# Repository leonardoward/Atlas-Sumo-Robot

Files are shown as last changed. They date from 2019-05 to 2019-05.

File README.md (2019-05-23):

# Atlas-Sumo-Robot

Software files for a Sumo Robot named Atlas, 2nd place in the VI National Robotics Competition, Sumo Category,  Venezuela 2016.

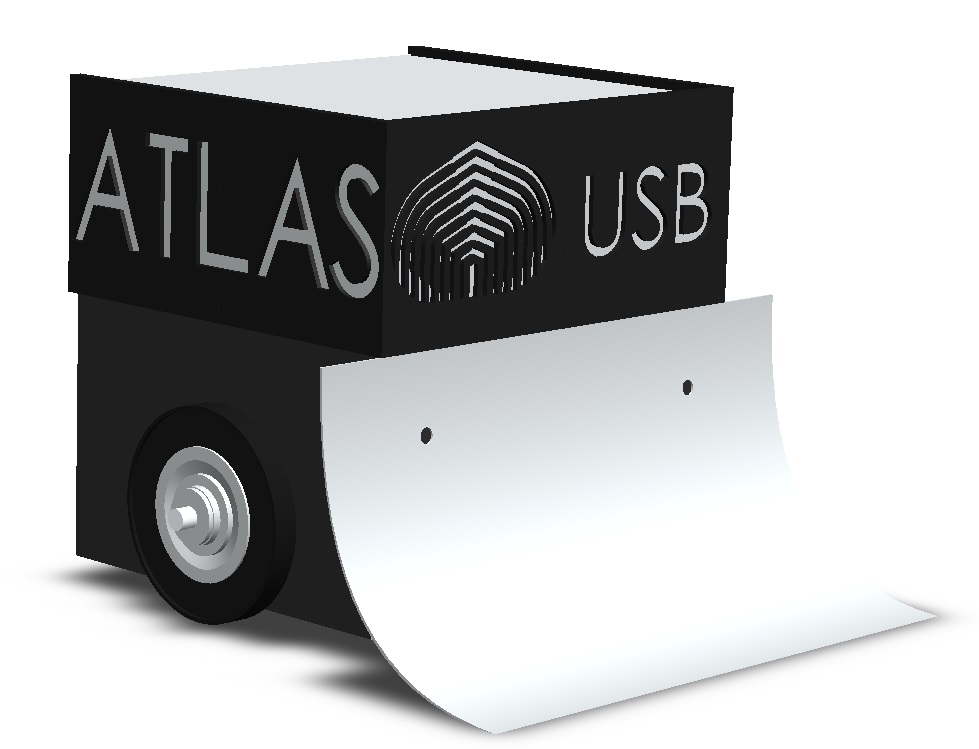
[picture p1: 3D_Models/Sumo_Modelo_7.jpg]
3D Model


## Authors

* **Leonardo Ward** -  [Github](https://github.com/leonardoward)
* **Javier Inojosa** -  [Github](https://github.com/javierinojosa)

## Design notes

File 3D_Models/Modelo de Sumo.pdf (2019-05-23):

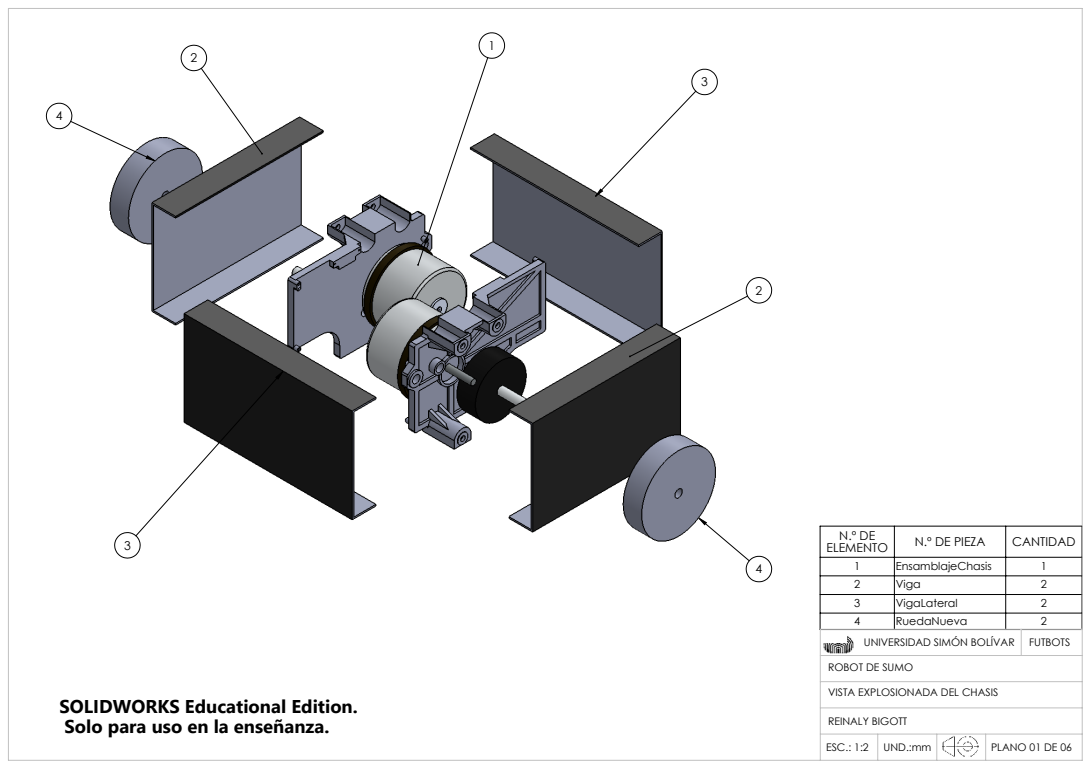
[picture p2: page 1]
REINALY BIGOTT; ESC.: 1:2; UND.:mm; PLANO 01 DE 06

N.º DE ELEMENTO | N.º DE PIEZA | CANTIDAD

1 | EnsamblajeChasis | 1
2 | Viga | 2
3 | VigaLateral | 2
4 | RuedaNueva | 2
UNIVERSIDAD SIMÓN BOLÍVAR | FUTBOTS

ROBOT DE SUMO
VISTA EXPLOSIONADA DEL CHASIS

SOLIDWORKS Educational Edition.
Solo para uso en la enseñanza.

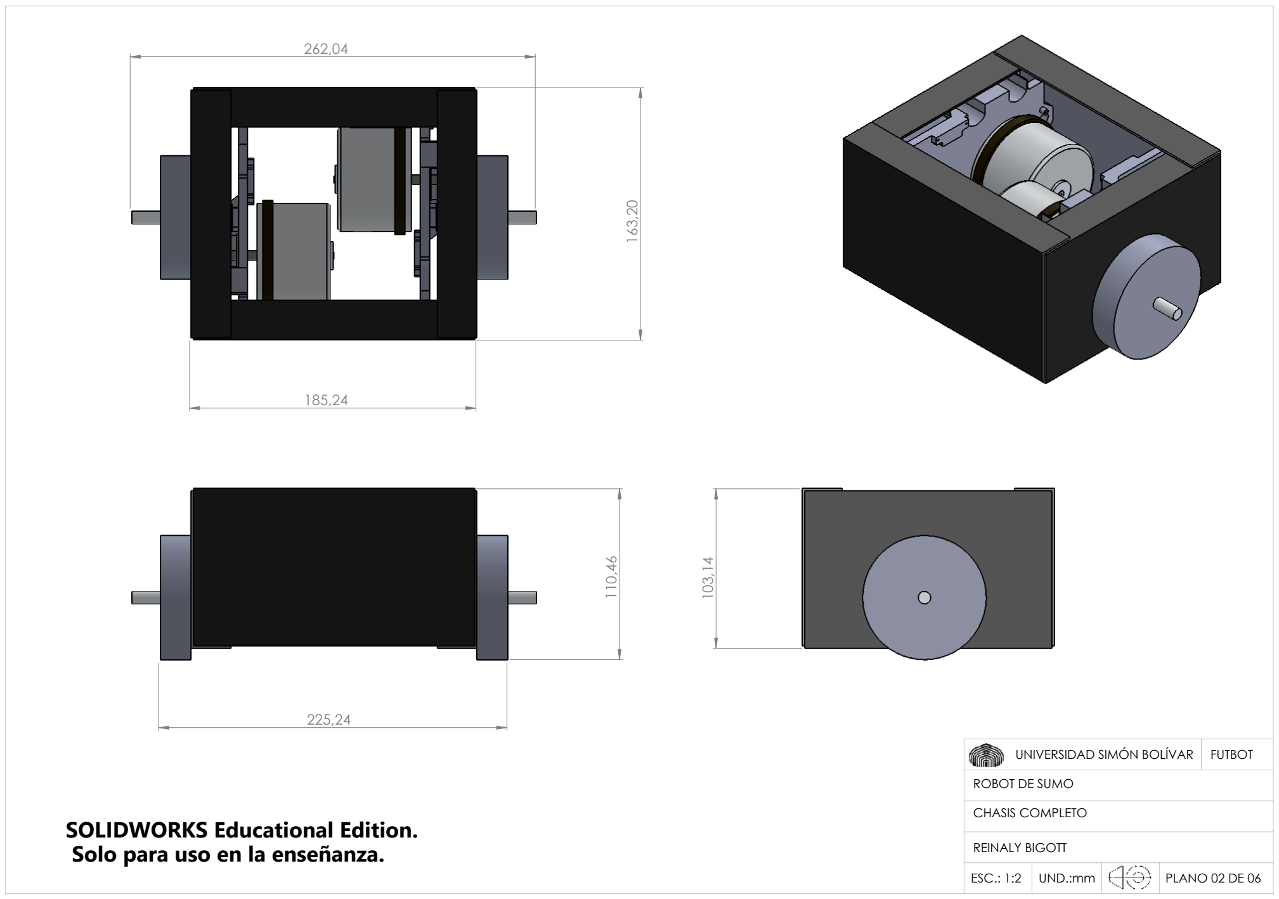
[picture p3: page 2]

225,24

110,46

163,20

185,24

103,14

UNIVERSIDAD SIMÓN BOLÍVAR FUTBOT ROBOT DE SUMO
CHASIS COMPLETO
SOLIDWORKS Educational Edition.

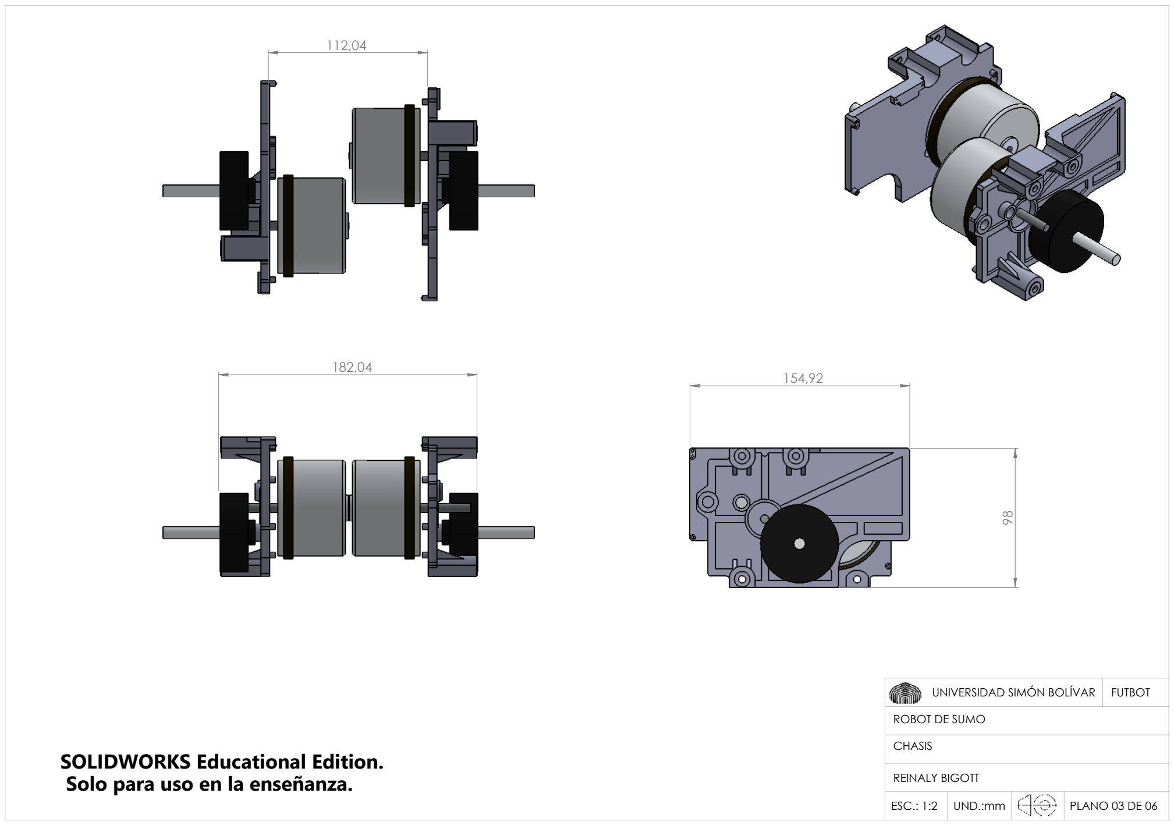
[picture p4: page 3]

182,04
154,92

98

UNIVERSIDAD SIMÓN BOLÍVAR FUTBOT ROBOT DE SUMO
CHASIS
SOLIDWORKS Educational Edition.

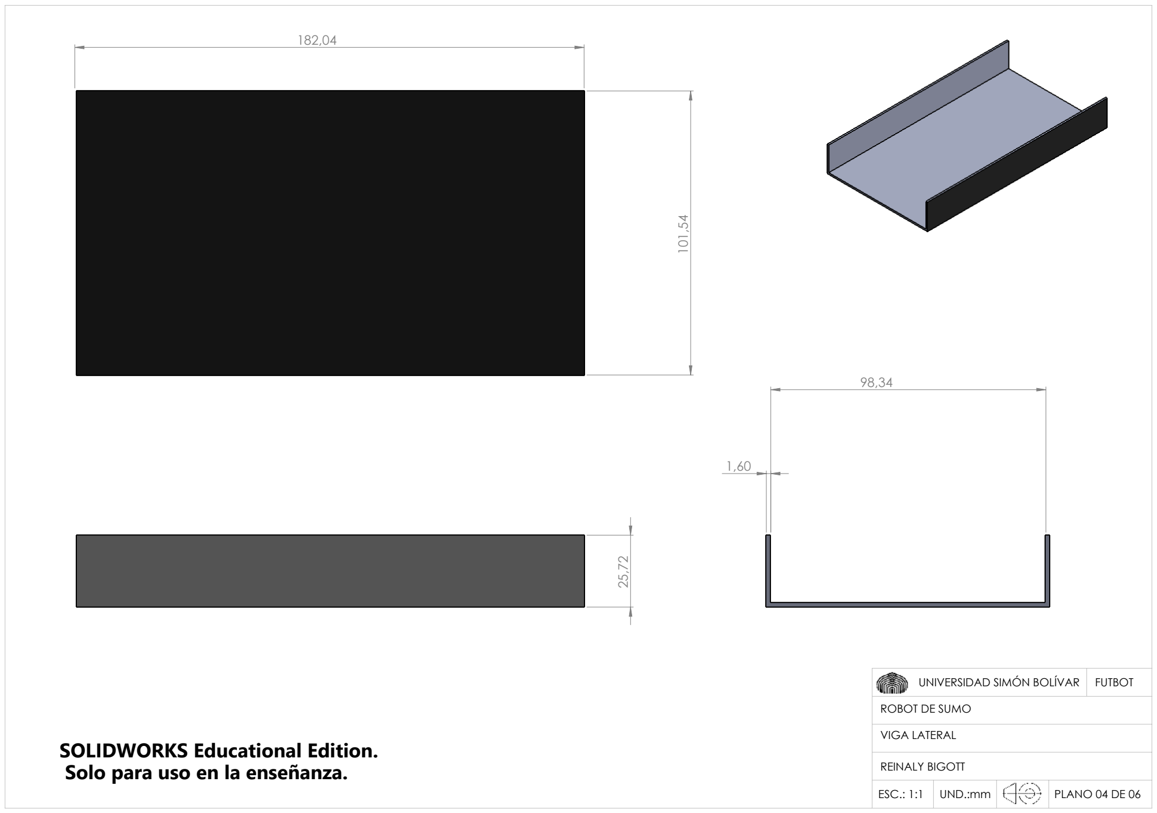
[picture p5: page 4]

25,72

101,54

1,60

98,34

UNIVERSIDAD SIMÓN BOLÍVAR FUTBOT ROBOT DE SUMO
VIGA LATERAL
ESC.: 1:1 | UND.:mm | PLANO 04 DE 06

SOLIDWORKS Educational Edition.

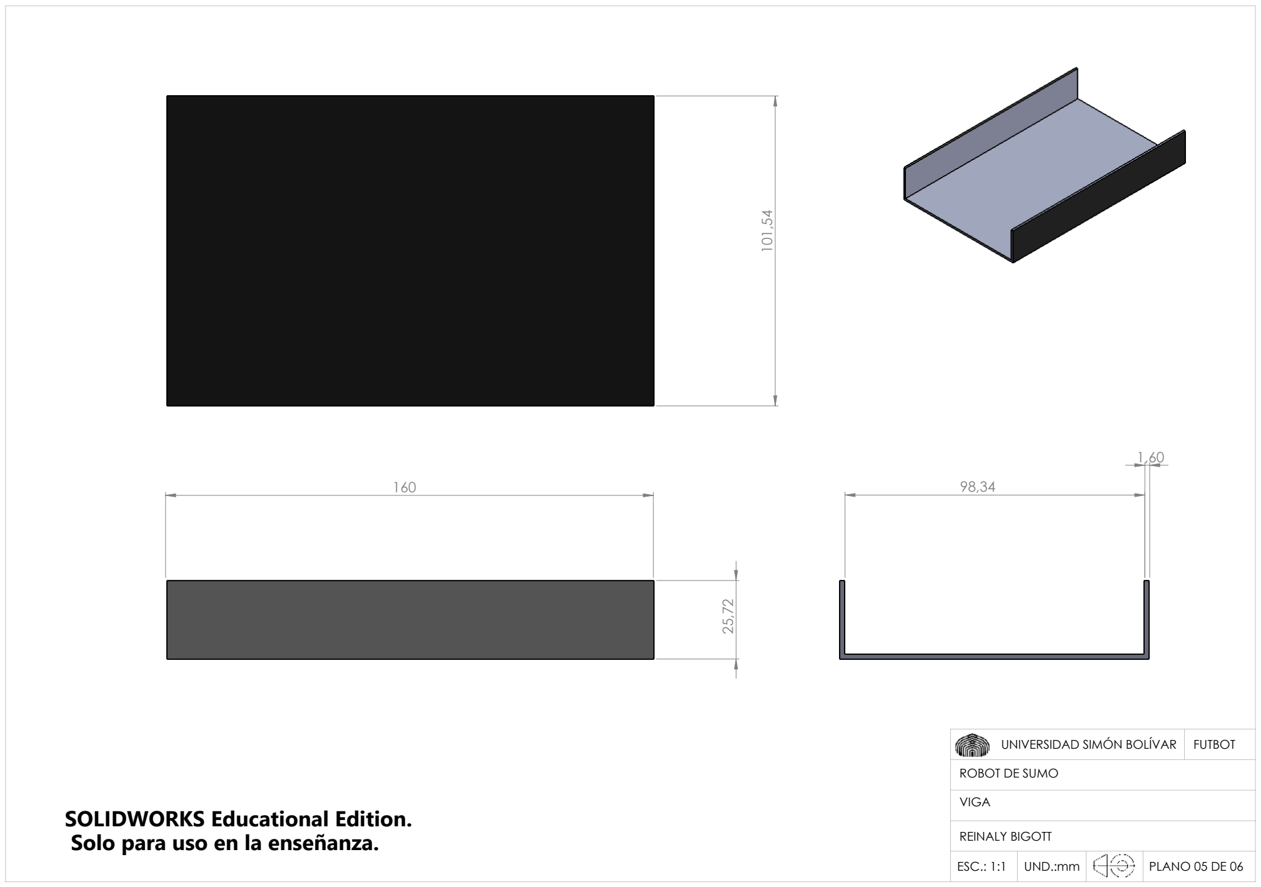
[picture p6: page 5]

160

25,72

98,34

1,60

101,54

UNIVERSIDAD SIMÓN BOLÍVAR FUTBOT ROBOT DE SUMO
VIGA
ESC.: 1:1 | UND.:mm | PLANO 05 DE 06

SOLIDWORKS Educational Edition.

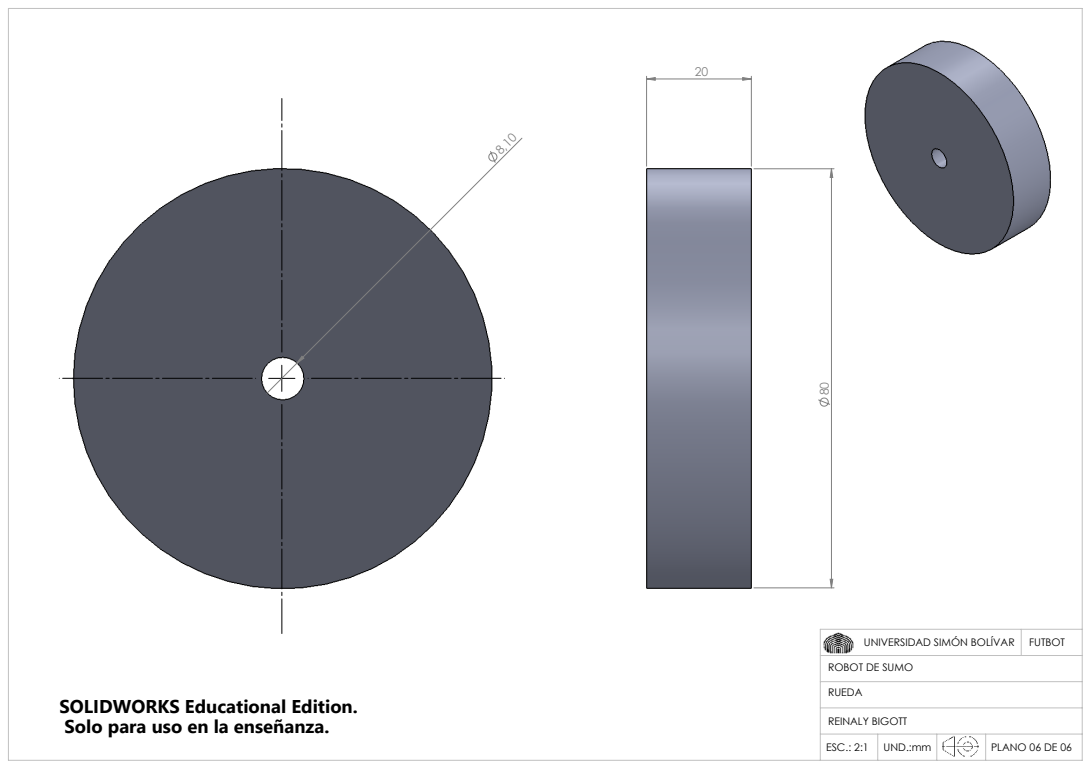
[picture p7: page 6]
UNIVERSIDAD SIMÓN BOLÍVAR; FUTBOT; ESC.: 2:1; UND.:mm; PLANO 06 DE 06

ROBOT DE SUMO
RUEDA

SOLIDWORKS Educational Edition.

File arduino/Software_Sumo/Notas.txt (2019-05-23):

-Todos los robots deben quedar funcionales, y cumplir con lo que se prometió para cada uno
-No va a haber inversión por ahora, por lo menos hasta ver los resultados de la primera inversión,
lo que falte se puede buscar aquí
-Se debe desarmar por completo el submarino para comenzar desde cero, y verificar que ninguna de las piezas
se haya dañado, una vez se verifique que todo lo comprado y las cosas de Pedro se encuentran en buen estado
se podrá comenzar desde cero.
-Es necesario quitarle el negro a todo el submarino de cualquier forma para que luego se pueda pintar del color que
vaya a tener al final, posiblemente amarillo
-Revisar el acrílico, que no debería tener pintura, debería estar en perfecto estado porque se colocó luego de pintar
-Considerar opciones, hacer maquinado con Gearca, pero no vamos a tener dinero para conseguir el material necesario para hacer el maquinado, debemos conseguirlo de cualquier modo, como fundir otras piezas, y si no se puede, entonces no habrá maquinado, tendran que construir cada parte con el aluminio que tenemos o que se pueda conseguir, y se paga la soldadura
-Se espera que el submarino se sumerja 10 o 20 metros
-Montar toda la electrónica fuera del submarino, para verlo todo funcionando, aunque no haya nada de la mecánica
-Análisis hidráulico del submarino

Actividades pendientes:
-Trabajo Cardiotune
-Tesis
-Comentar código del robot de sumo
-Electiva solar

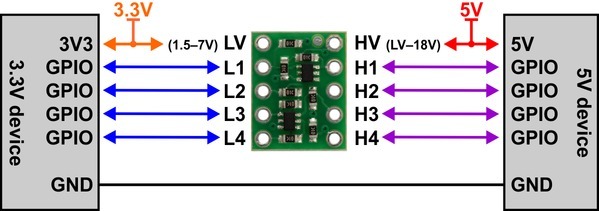
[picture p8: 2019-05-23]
Electronics_Design/Electronica/0J5318.599.jpg

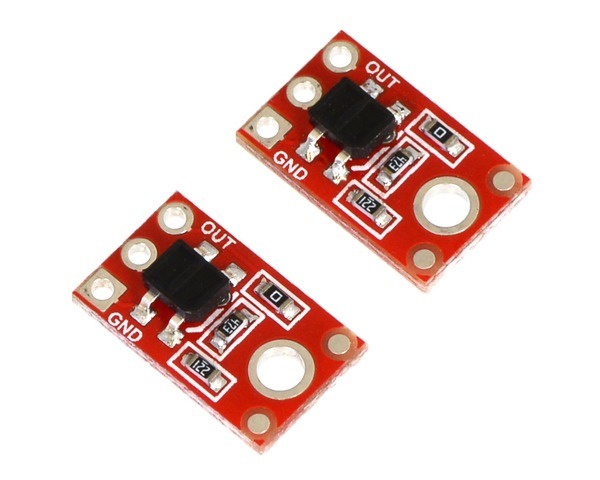
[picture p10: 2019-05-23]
Electronics_Design/Electronica/QTR-1A reflectance sensors.jpg

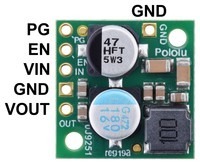
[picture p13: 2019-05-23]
Electronics_Design/Electronica/0J6802.200.jpg

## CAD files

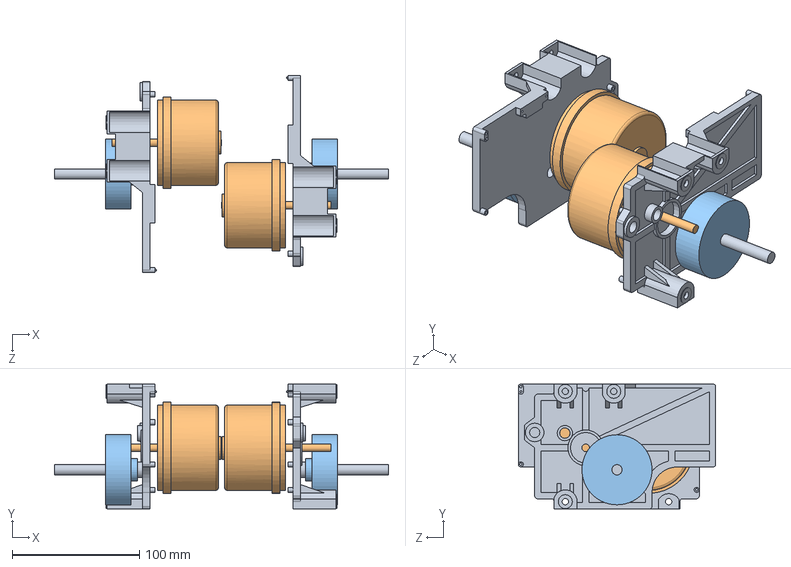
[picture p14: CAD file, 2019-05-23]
3D_Models/Version 3/EnsamblajeChasis.SLDASM
262.0 x 98.0 x 154.9 mm
BaseMotorDeSumo-Copia x 2
MotorDeSumo x 2
EngranajeNegroCentralModificado x 2

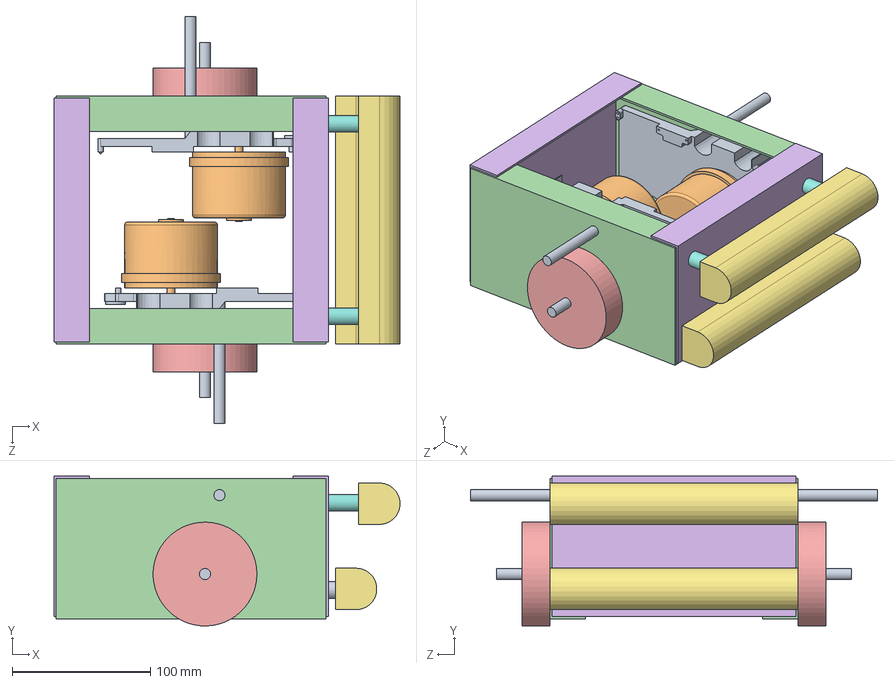
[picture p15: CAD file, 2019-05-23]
3D_Models/Rampa Alternativa/EnsamblajeNuevoConRampa.SLDASM
249.9 x 108.3 x 294.0 mm
BaseMotorDeSumo x 2
MotorDeSumo x 2
EngranajeNegroCentralModificado x 2
Viga x 2
RuedaNueva x 2
VigaLateral x 2
PiezaDeBloqueo x 2
Tubo x 2
Tubo2 x 2

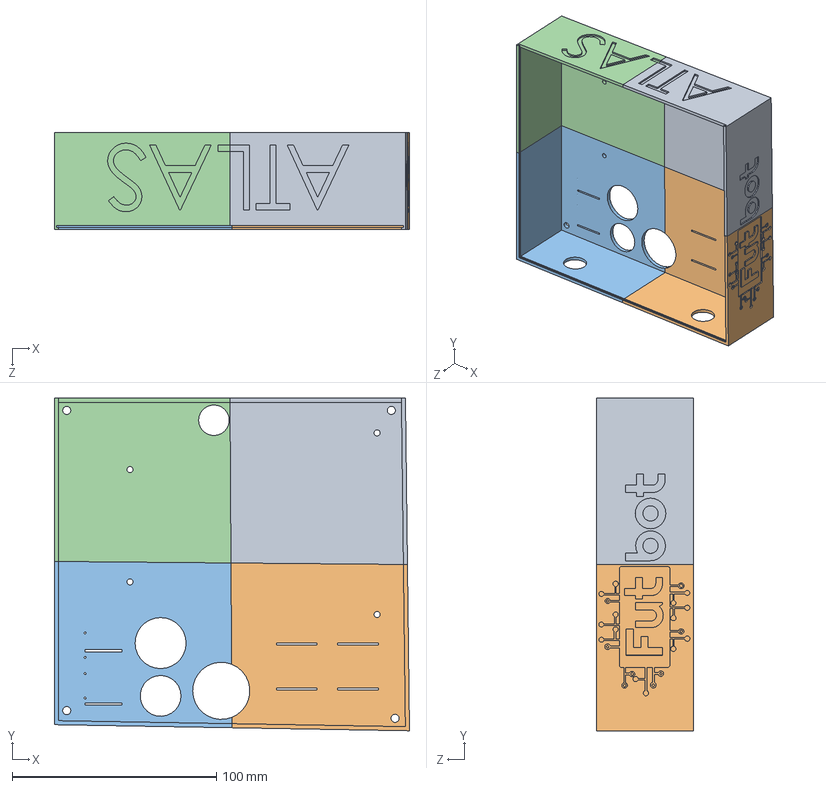
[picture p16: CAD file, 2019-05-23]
3D_Models/Caja y rueda/Caja 3D.SLDASM
174.0 x 163.0 x 47.5 mm
Pieza N°1
Pieza N°2
Pieza N°3
Pieza N°4

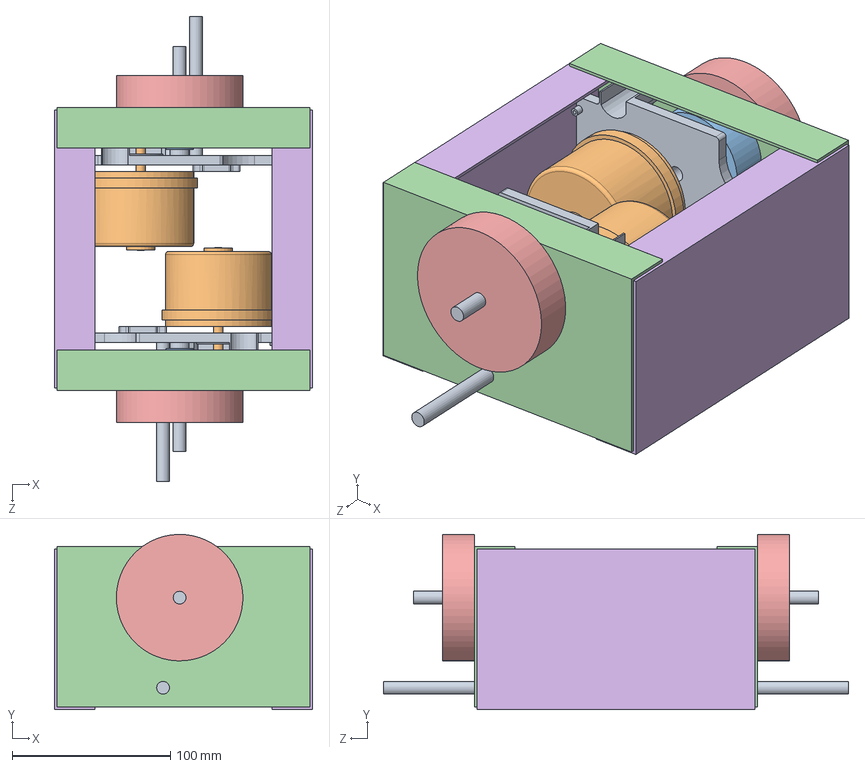
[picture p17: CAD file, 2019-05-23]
3D_Models/Version 3/EnsamblajeNuevoChasis.SLDASM
163.2 x 110.8 x 294.0 mm
BaseMotorDeSumo x 2
MotorDeSumo x 2
EngranajeNegroCentralModificado x 2
Viga x 2
RuedaNueva x 2
VigaLateral x 2

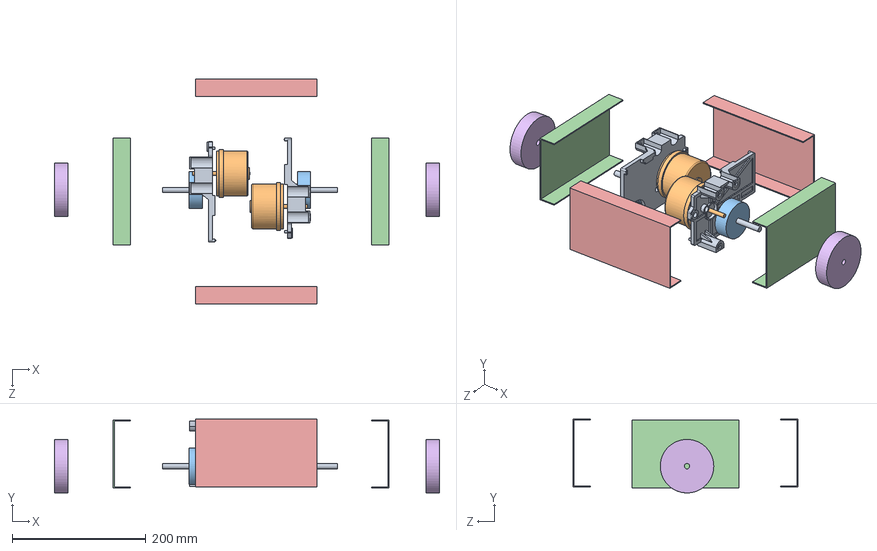
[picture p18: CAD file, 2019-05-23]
3D_Models/Version 3/EnsamblajeChasis1.SLDASM
575.8 x 110.5 x 336.1 mm
BaseMotorDeSumo-Copia x 2
MotorDeSumo x 2
EngranajeNegroCentralModificado x 2
Viga x 2
VigaLateral x 2
RuedaNueva x 2

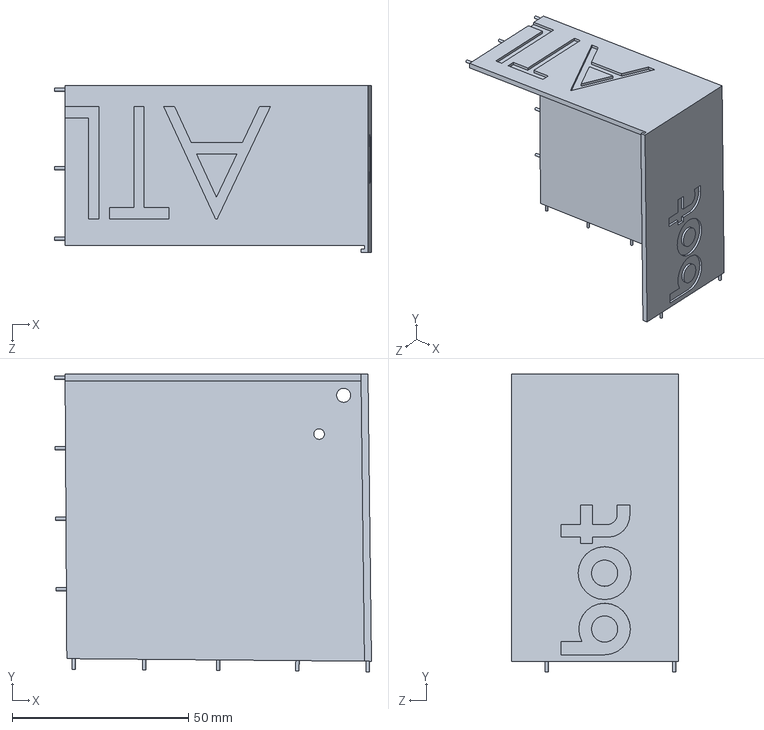
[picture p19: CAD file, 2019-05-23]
3D_Models/Caja y rueda/Pieza N°1.SLDPRT
90.0 x 84.5 x 47.5 mm

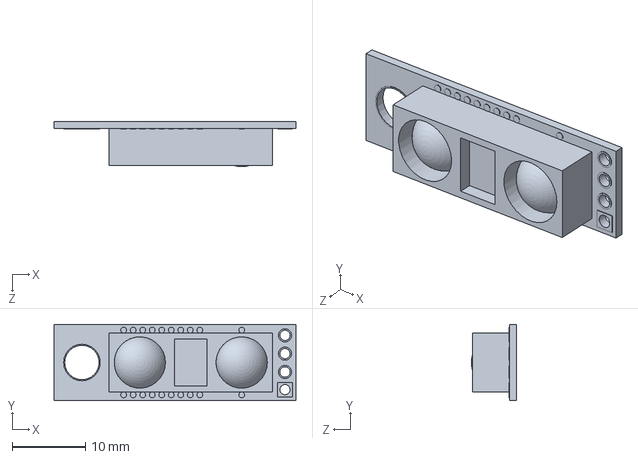
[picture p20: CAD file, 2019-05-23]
3D_Models/Electronica/PololuCarrierWithSharpGP2Y0A60SZLFAnalogDistanceSensor10-150cm,5V.SLDPRT
33.0 x 10.4 x 6.20 mm

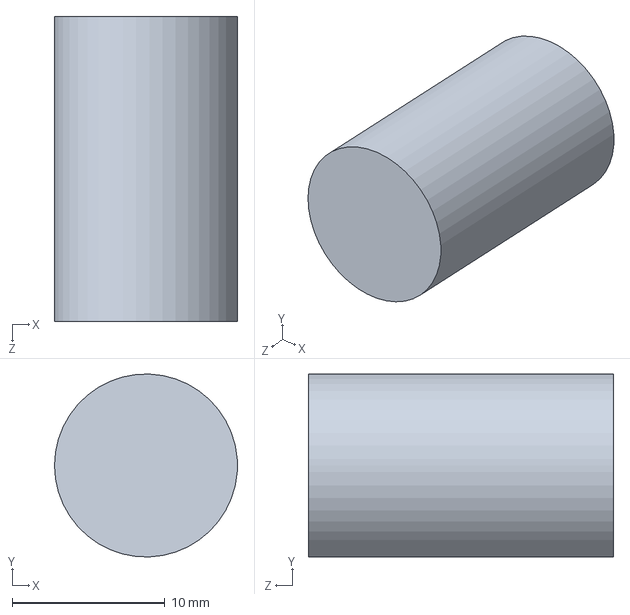
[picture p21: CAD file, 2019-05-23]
3D_Models/Rampa Alternativa/Tubo2.SLDPRT
12.0 x 12.0 x 20.0 mm

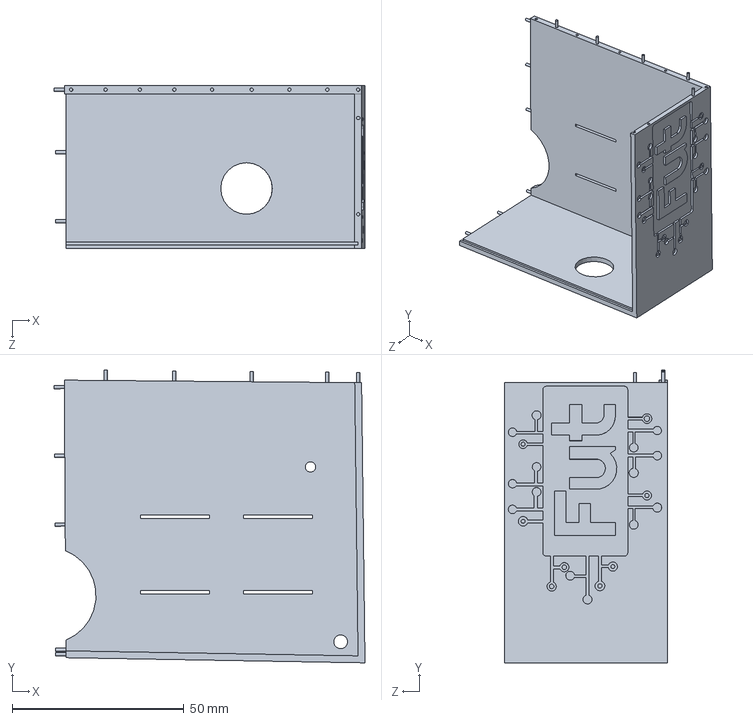
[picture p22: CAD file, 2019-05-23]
3D_Models/Caja y rueda/Pieza N°2.SLDPRT
90.5 x 85.1 x 47.5 mm

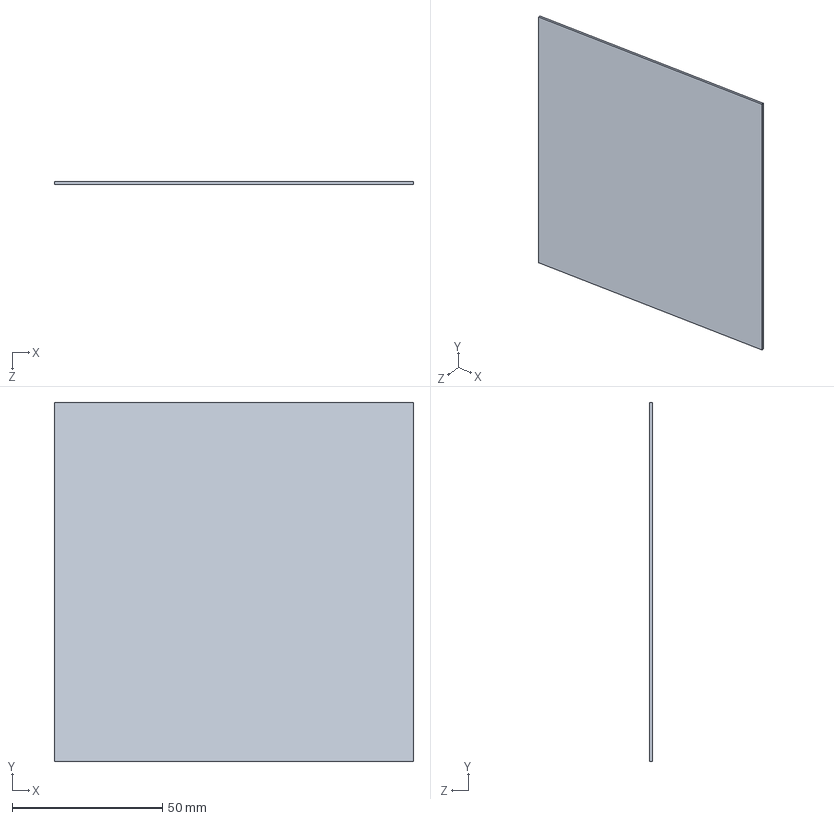
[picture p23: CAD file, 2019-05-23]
3D_Models/Electronica/RaspberryPiCameraModuleV2-8Megapixel,1080p.SLDPRT
119.4 x 119.4 x 1.00 mm

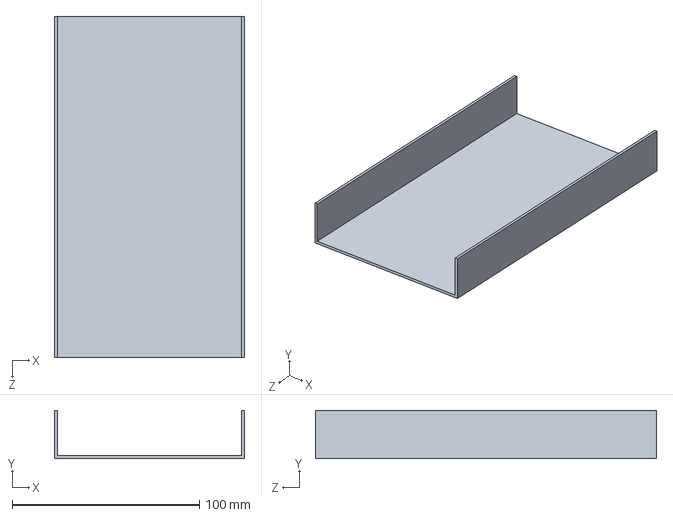
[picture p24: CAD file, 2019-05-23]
3D_Models/Version 3/VigaLateral.SLDPRT
101.5 x 25.7 x 182.0 mm

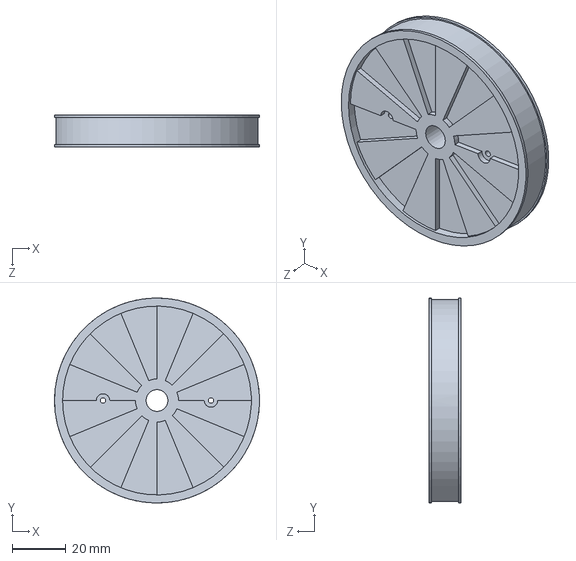
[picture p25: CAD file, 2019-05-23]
3D_Models/Caja y rueda/Rueda 3D.SLDPRT
76.0 x 76.0 x 12.0 mm

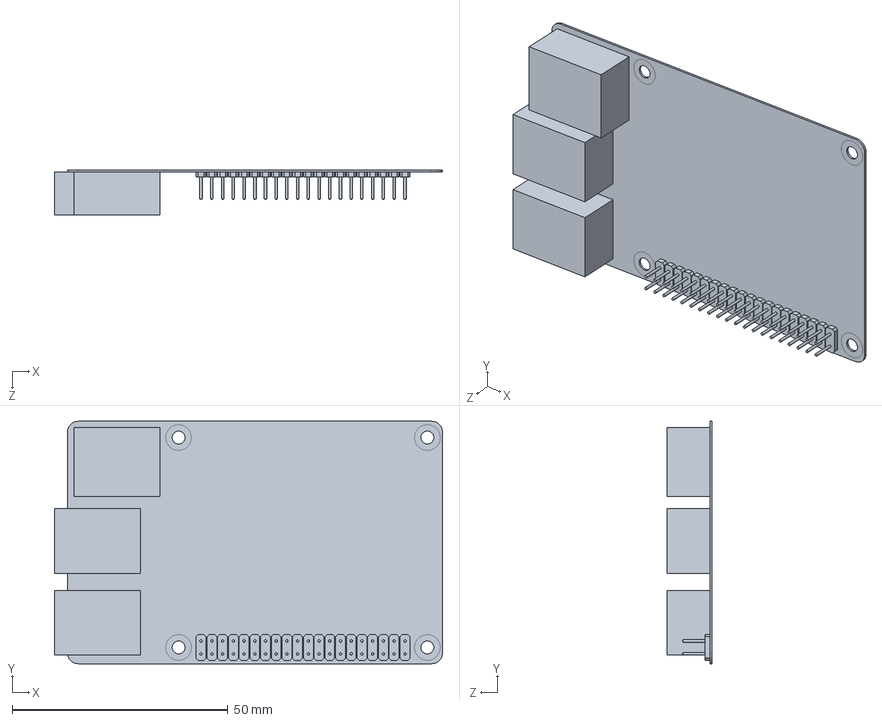
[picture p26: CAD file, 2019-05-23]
3D_Models/Electronica/RaspberryPiModelo3.SLDPRT
90.0 x 56.3 x 10.5 mm

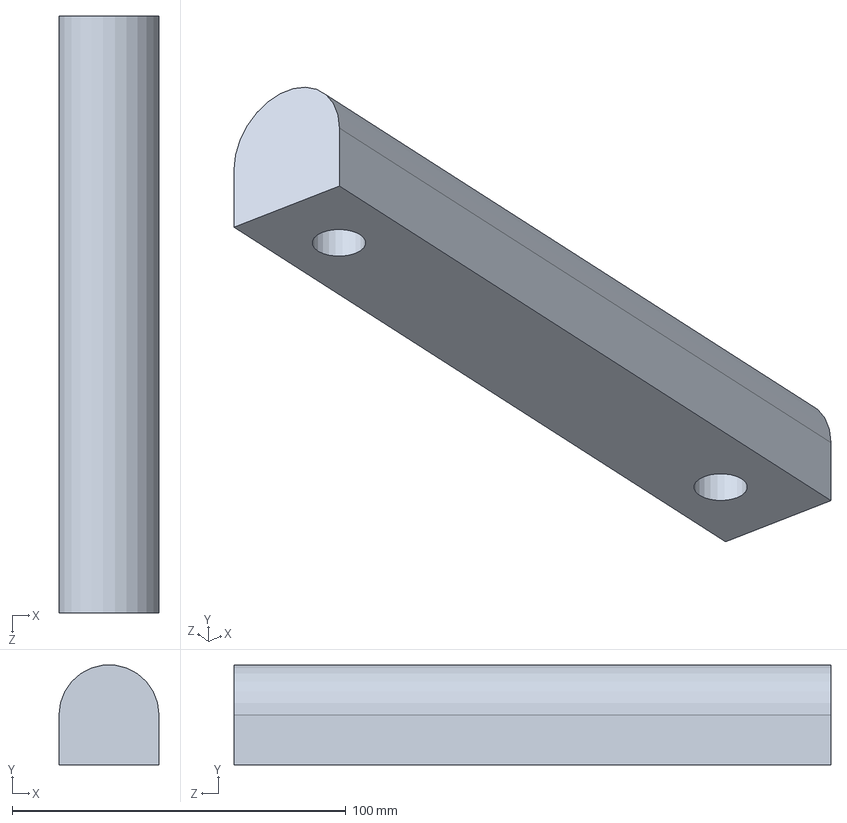
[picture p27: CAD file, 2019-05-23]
3D_Models/Rampa Alternativa/PiezaDeBloqueo.SLDPRT
30.0 x 29.9 x 179.0 mm

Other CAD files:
3D_Models/Croquis Guia.SLDPRT
3D_Models/Caja y rueda/Pieza N°3.SLDPRT
3D_Models/Electronica/3xNanoV3.0ATmega328.SLDPRT
3D_Models/Rampa Alternativa/Tubo.SLDPRT
3D_Models/Caja y rueda/Croquis Guia.SLDPRT
3D_Models/Caja y rueda/Pieza N°4.SLDPRT
3D_Models/Caja y rueda/Rueda 3D.STL
3D_Models/Electronica/LiPoBattery.SLDPRT
3D_Models/Electronica/LogicLevelShifter,4-Channel,Bidirectional.SLDPRT
3D_Models/Electronica/Pololu5V,2.5AStep-DownVoltageRegulatorD24V22F5.SLDPRT
3D_Models/Electronica/PololuAdjustable9-30VStep-UpVoltageRegulatorU3V50AHV.SLDPRT
3D_Models/Electronica/QTR-1AReflectanceSensor.SLDPRT
3D_Models/Electronica/RollerBallTransfer(rueda loca).SLDPRT
3D_Models/Rampa/OldVersions/Rampa Lápices 2.0002.ipt
3D_Models/Rampa/OldVersions/Rampa Lápices.0015.ipt
3D_Models/Rampa/Rampa Lápices 2.ipt
3D_Models/Rampa/Rampa Lápices.ipt
3D_Models/Version 1/Robot de Sumo/AcopleBaseMotorSumo.SLDPRT
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

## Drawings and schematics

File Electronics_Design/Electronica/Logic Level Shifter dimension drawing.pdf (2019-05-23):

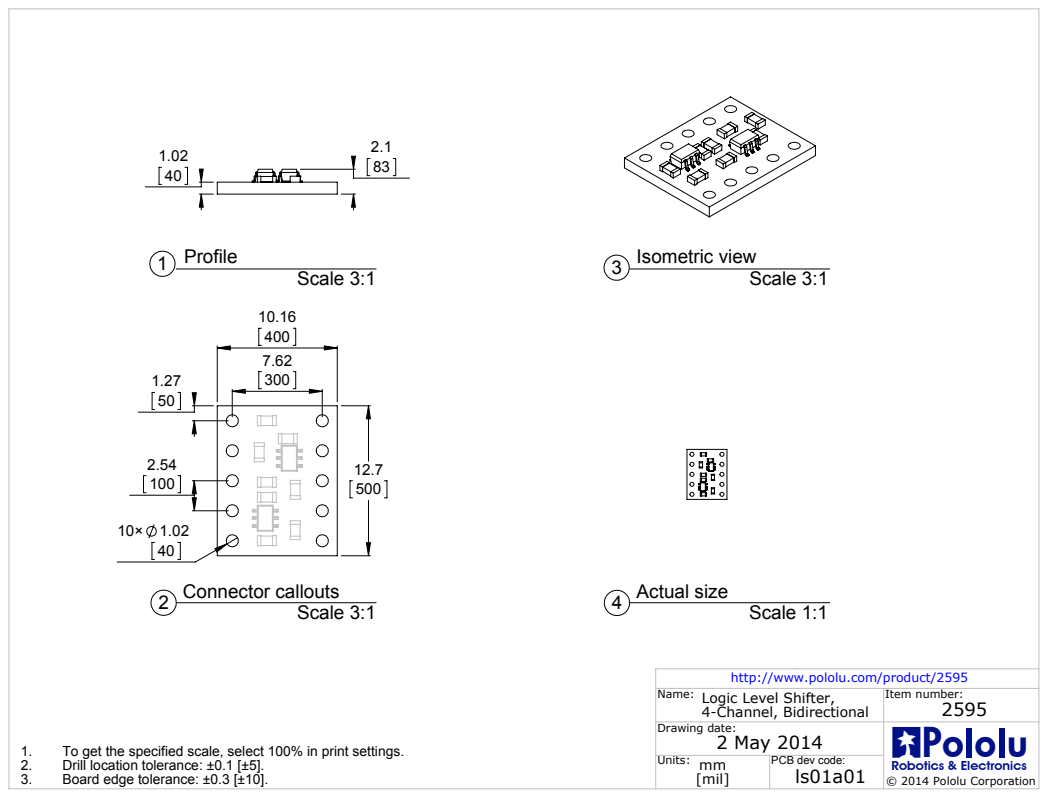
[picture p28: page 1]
Actual size; Scale 3:1; Scale 1:1; Isometric view; Connector callouts

http://www.pololu.com/product/2595

Name: 4-Channel, Bidirectional | Item number: 2595 Logic Level Shifter,
Drawing date: 2 May 2014 | l l Po o u Robotics & Electronics © 2014 Pololu Corporation

1. To get the specified scale, select 100% in print settings.
2. Drill location tolerance: ±0.1 [±5].
3. Board edge tolerance: ±0.3 [±10].

Units: mm [mil] | PCB dev code: ls01a01

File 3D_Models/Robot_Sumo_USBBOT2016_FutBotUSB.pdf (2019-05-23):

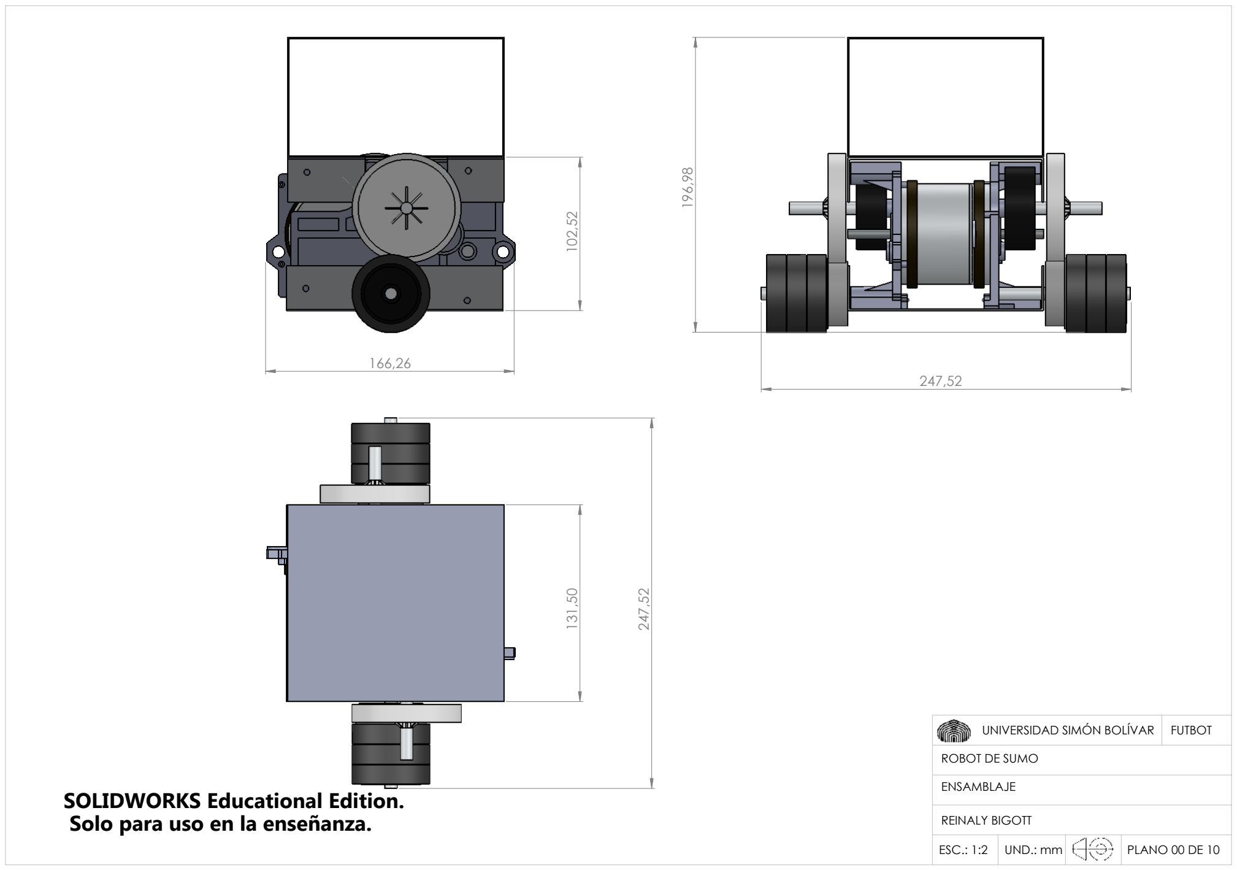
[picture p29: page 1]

166,26

102,52

196,98

247,52

131,50

247,52

UNIVERSIDAD SIMÓN BOLÍVAR FUTBOT ROBOT DE SUMO
ENSAMBLAJE

REINALY BIGOTT

ESC.: 1:2 | UND.: mm | PLANO 00 DE 10

SOLIDWORKS Educational Edition. Solo para uso en la enseñanza.

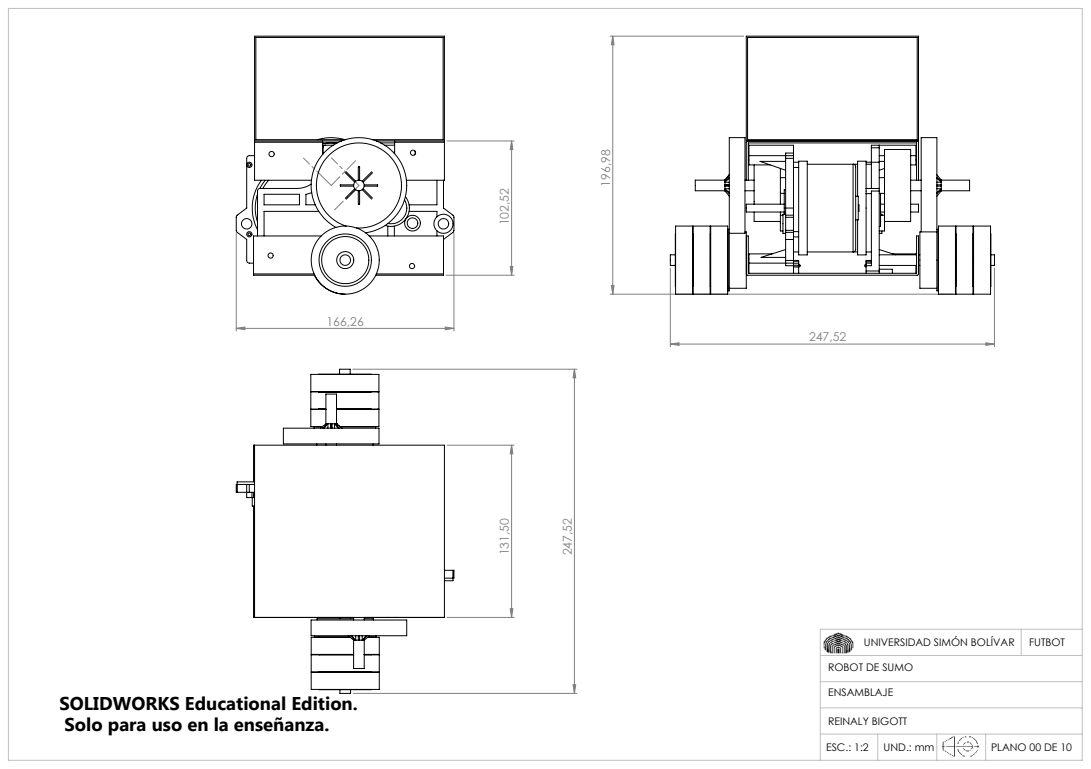
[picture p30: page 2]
UNIVERSIDAD SIMÓN BOLÍVAR; FUTBOT; ESC.: 1:2; UND.: mm; PLANO 00 DE 10

ROBOT DE SUMO
ENSAMBLAJE

SOLIDWORKS Educational Edition.

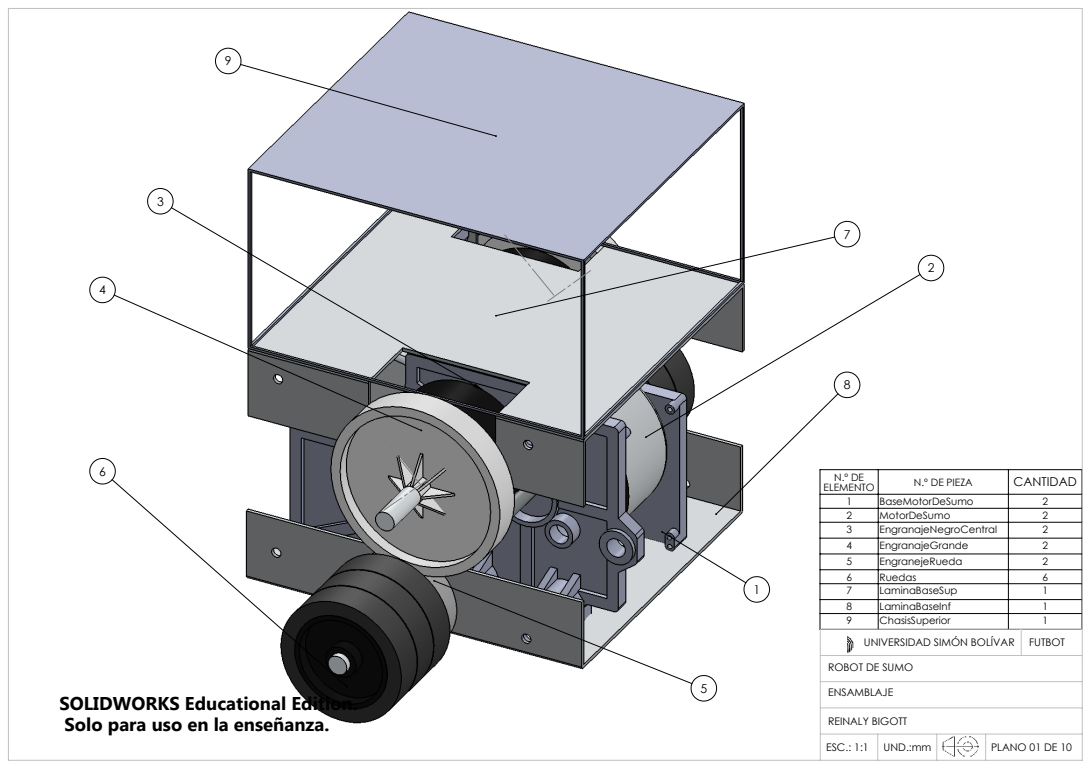
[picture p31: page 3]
ESC.: 1:1; UND.:mm; PLANO 01 DE 10

N.º DE ELEMENTO | N.º DE PIEZA | CANTIDAD
1 | BaseMotorDeSumo | 2
2 | MotorDeSumo | 2
3 | EngranajeNegroCentral | 2
4 | EngranajeGrande | 2
5 | EngranejeRueda | 2
6 | Ruedas | 6
7 | LaminaBaseSup | 1
8 | LaminaBaseInf | 1
9 | ChasisSuperior | 1
UNIVERSIDAD SIMÓN BOLÍVAR | FUTBOT

ROBOT DE SUMO
ENSAMBLAJE

SOLIDWORKS Educational Edition.

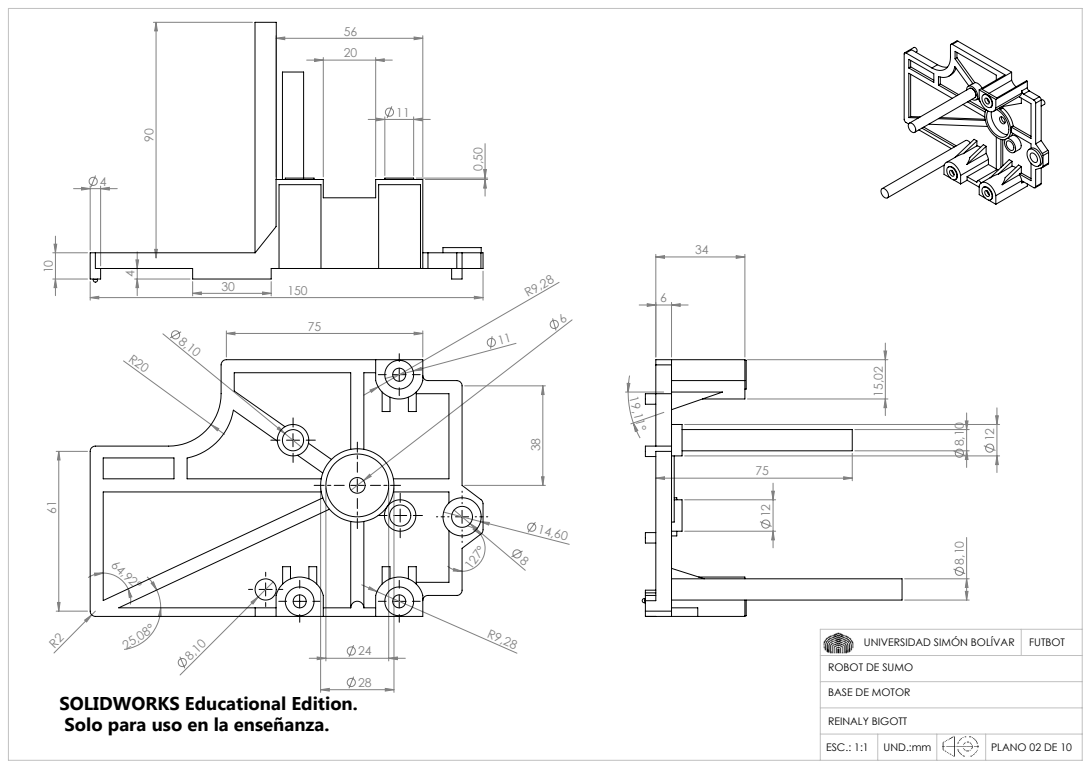
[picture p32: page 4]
UNIVERSIDAD SIMÓN BOLÍVAR; FUTBOT

ROBOT DE SUMO
BASE DE MOTOR

SOLIDWORKS Educational Edition.

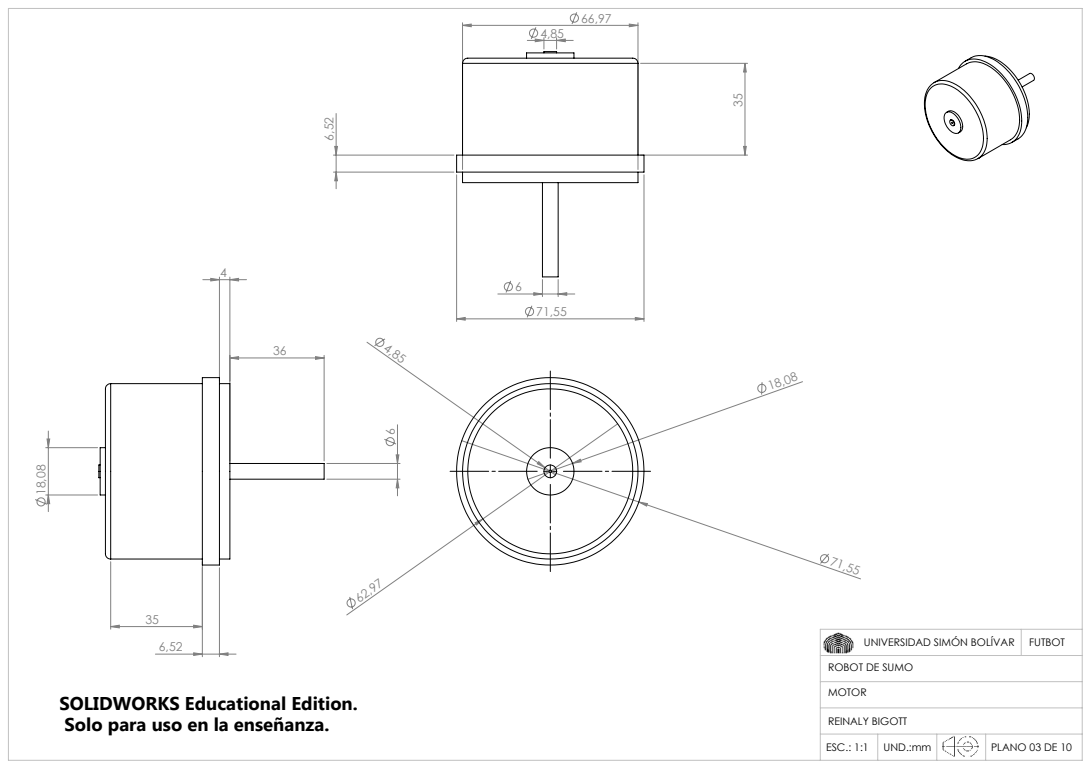
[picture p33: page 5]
UNIVERSIDAD SIMÓN BOLÍVAR; FUTBOT

ROBOT DE SUMO
MOTOR

SOLIDWORKS Educational Edition.

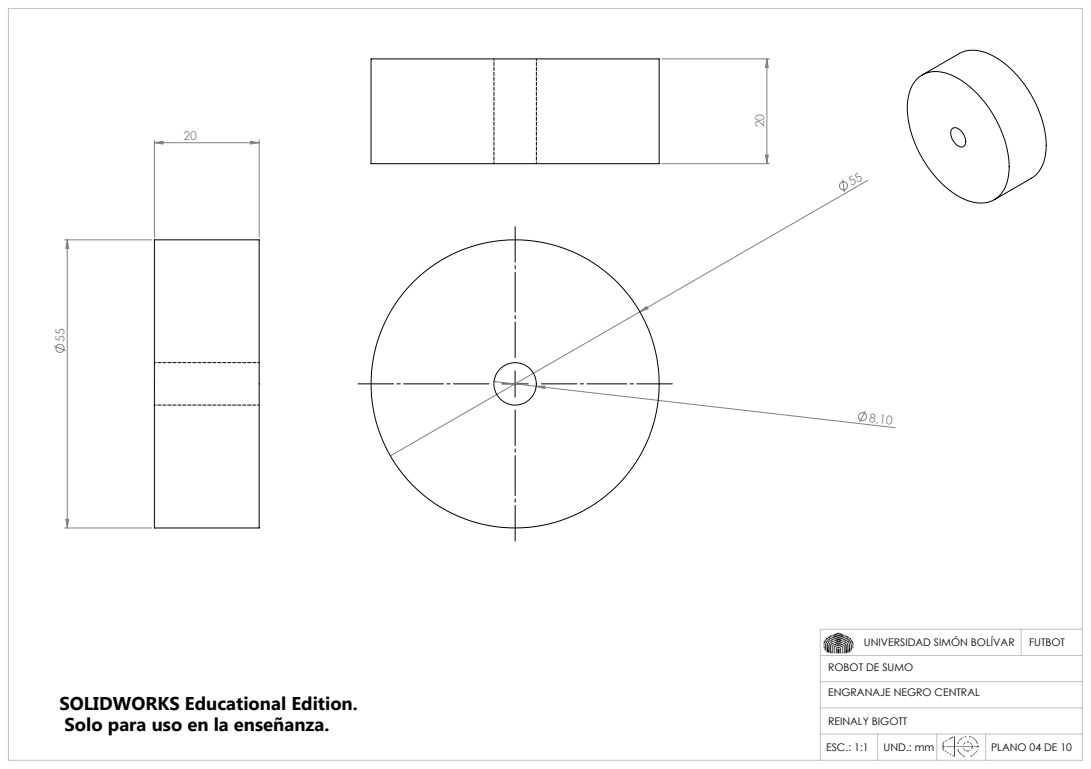
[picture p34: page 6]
UNIVERSIDAD SIMÓN BOLÍVAR; FUTBOT; ESC.: 1:1; UND.: mm; PLANO 04 DE 10

ROBOT DE SUMO
ENGRANAJE NEGRO CENTRAL

SOLIDWORKS Educational Edition.

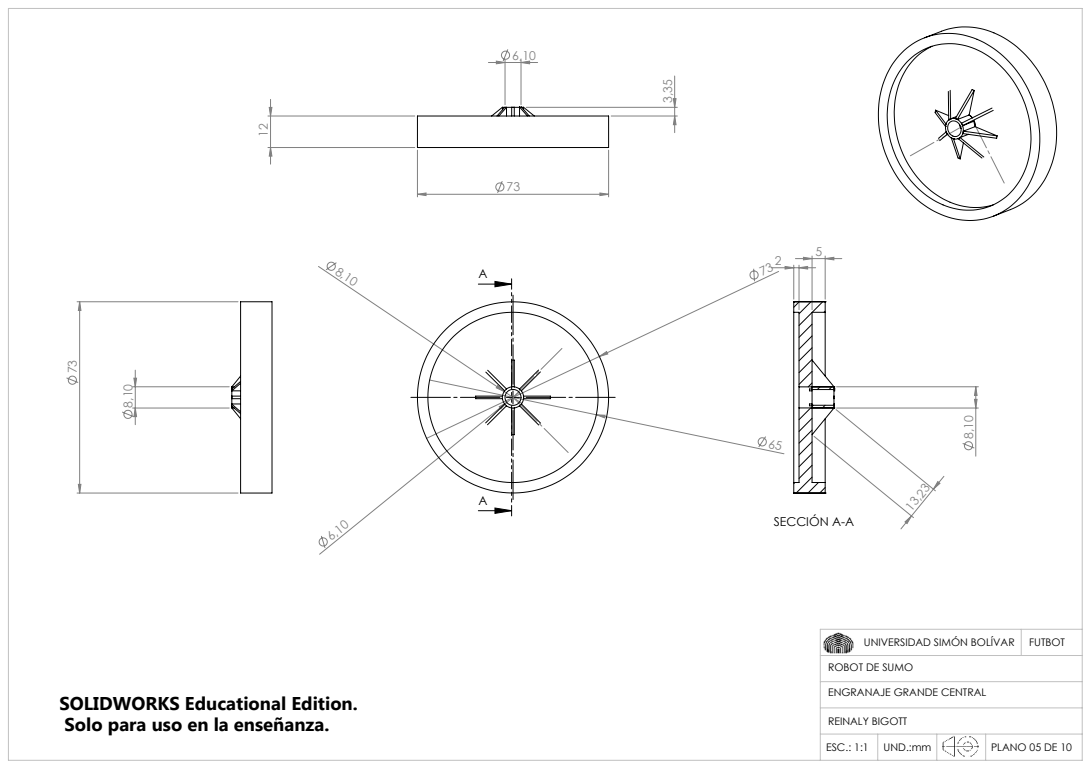
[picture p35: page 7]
SECCIÓN A-A; UNIVERSIDAD SIMÓN BOLÍVAR; FUTBOT

ROBOT DE SUMO
ENGRANAJE GRANDE CENTRAL

SOLIDWORKS Educational Edition.

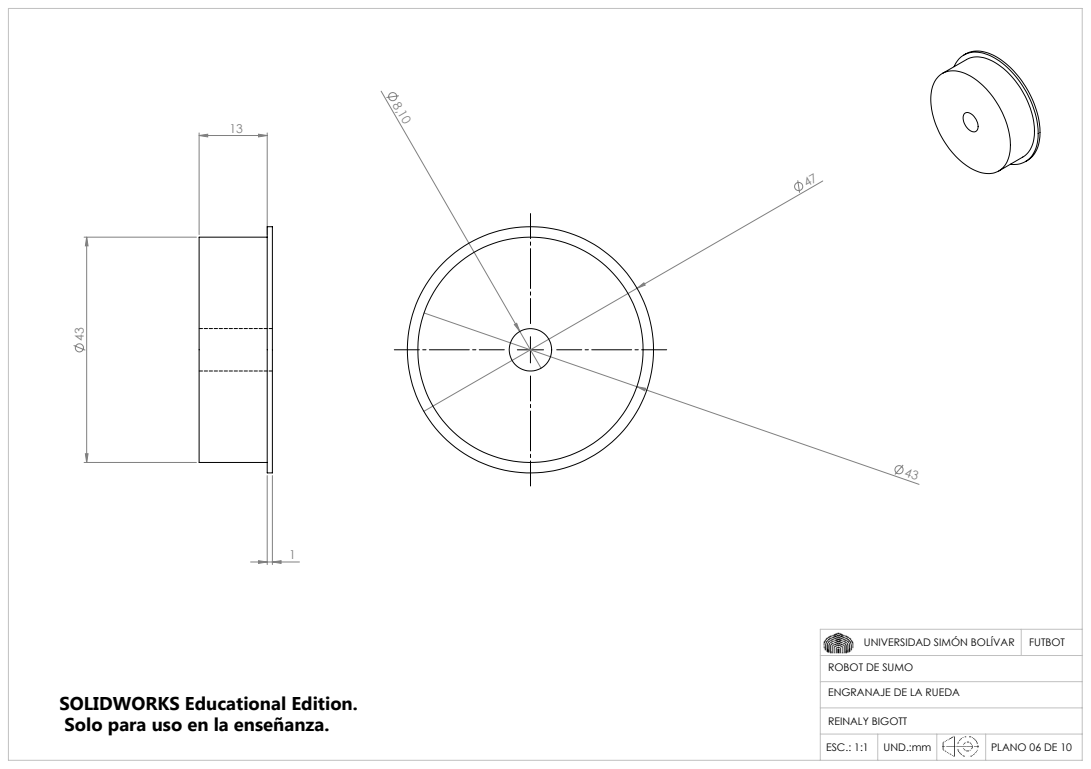
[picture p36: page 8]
UNIVERSIDAD SIMÓN BOLÍVAR; FUTBOT

ROBOT DE SUMO
ENGRANAJE DE LA RUEDA

SOLIDWORKS Educational Edition.

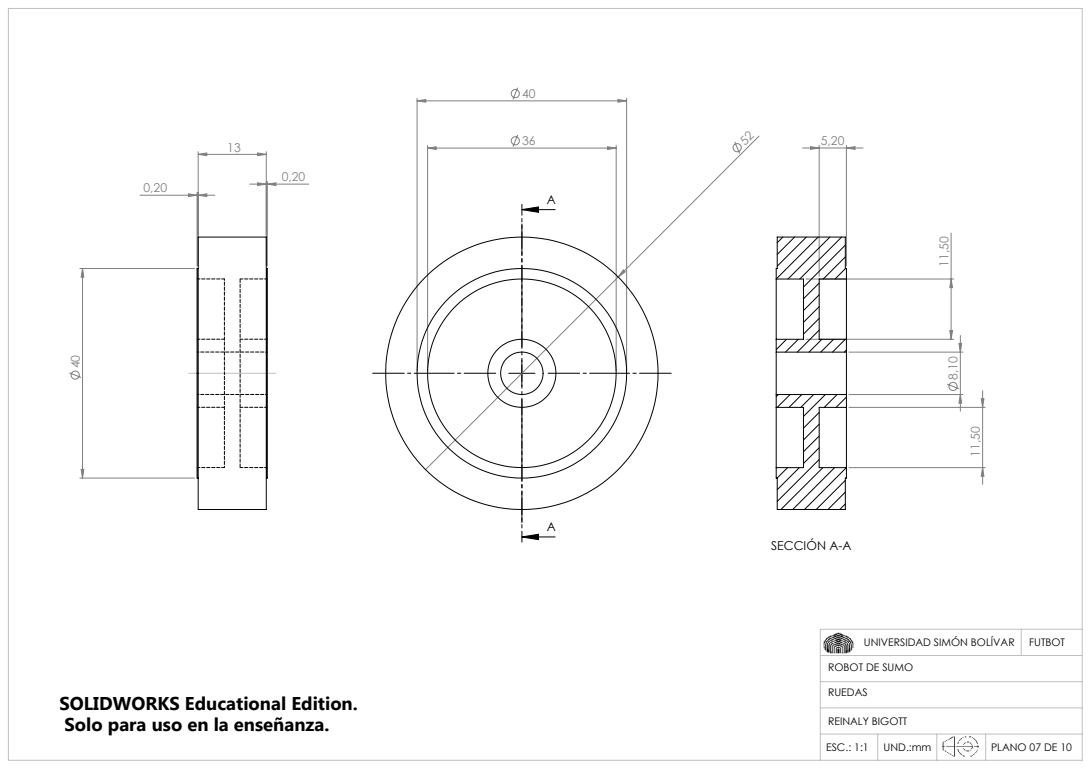
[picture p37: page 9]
SECCIÓN A-A; UNIVERSIDAD SIMÓN BOLÍVAR; FUTBOT

ROBOT DE SUMO
RUEDAS

SOLIDWORKS Educational Edition.

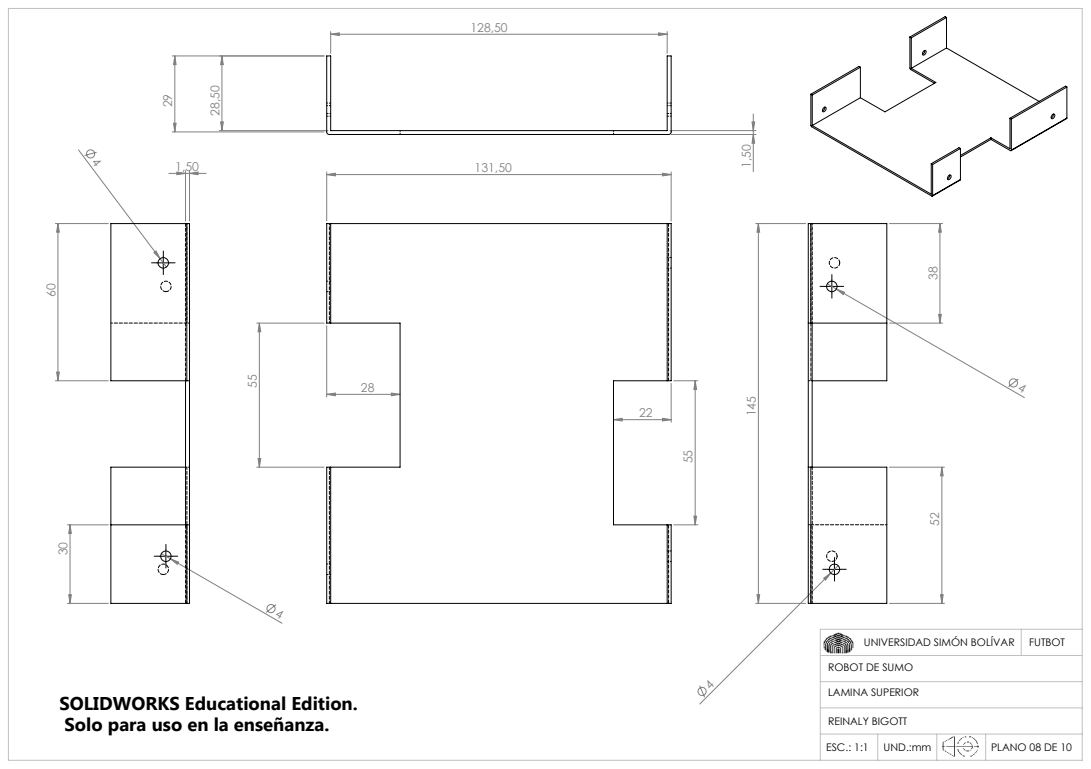
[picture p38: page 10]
UNIVERSIDAD SIMÓN BOLÍVAR; FUTBOT

ROBOT DE SUMO
LAMINA SUPERIOR

SOLIDWORKS Educational Edition.

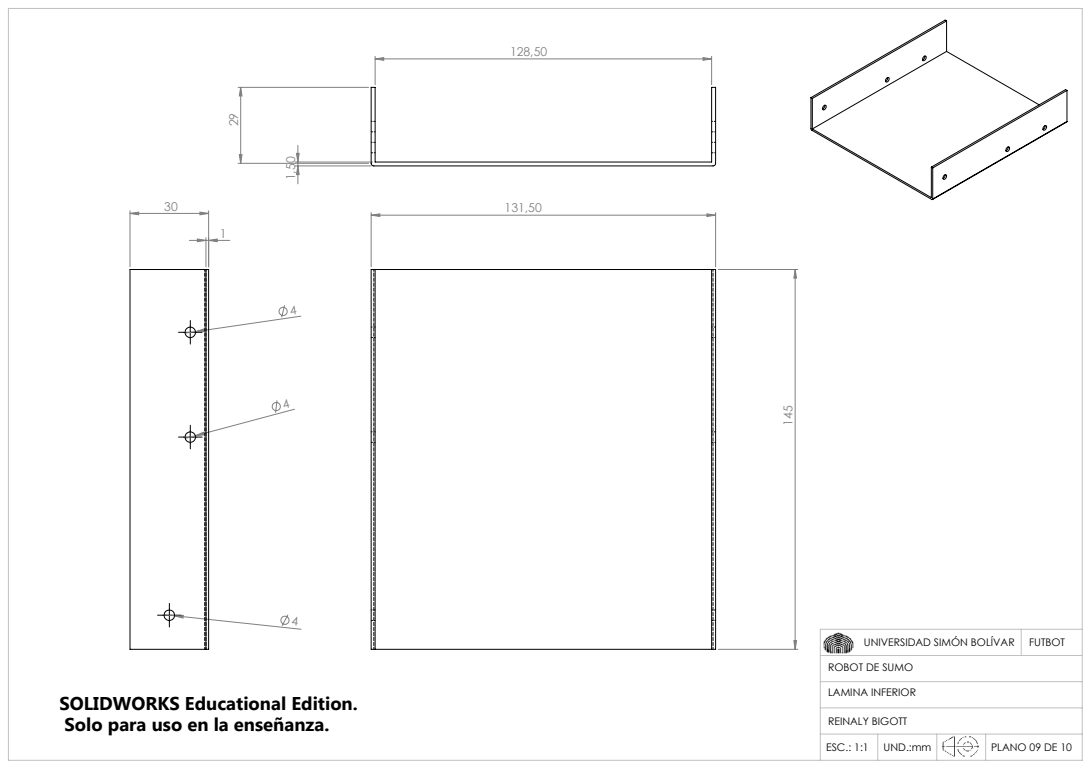
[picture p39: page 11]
UNIVERSIDAD SIMÓN BOLÍVAR; FUTBOT

ROBOT DE SUMO
LAMINA INFERIOR

SOLIDWORKS Educational Edition.

UNIVERSIDAD SIMÓN BOLÍVAR; FUTBOT; ESC.: 1:1; UND.: mm; PLANO 10 DE 10

ROBOT DE SUMO
CHASIS SUPERIOR

SOLIDWORKS Educational Edition.




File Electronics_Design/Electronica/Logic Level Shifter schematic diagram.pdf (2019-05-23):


Logic Level Shifter, 4-Channel, Bidirectional

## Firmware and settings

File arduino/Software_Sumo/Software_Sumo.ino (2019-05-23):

/*
########################################################################################################################
##                                       Software Robot de SUMO                                                       ##
##                                                                                                                    ##
## FutBot - Future Robotics                                                                                           ##
## Universidad Nacional Experimental Simon Bolivar                                                                    ##
## Venezuela, 2016                                                                                                    ##
########################################################################################################################
*/
#include <SPI.h>
#include <TimerOne.h>
#include <PID_v1.h>

#define ENC_M1 2
#define ENC_M2 3
#define FR_M2 4
#define PWM_M1 5
#define PWM_M2 6
#define EN_M1 7
#define FR_M1 8
#define EN_M2 9

#define SHARP_1 A0
#define SHARP_2 A1
#define SHARP_3 A2
#define SHARP_4 A3
#define CURRENT_M1 A4
#define CURRENT_M2 A5

#define chipSelectPin 10

#define CURRENT_LIMIT 3.5

#define Vcc_  4.99
#define vref_pos 4.99
#define vref_neg 0

#define TiempoDeMuestreo 100
#define div_por_vuelta 30

#define FACTOR_DECENSO_PID 10

#define RADIUS_WHEEL 0.08 //En m
#define LENGTH_ROBOT 0.25 //En m

#define RPM_MAX 2000 //En rpm
#define W_MAX 115.19 //En rad/s

#define Sharp_Front_Center 2
#define Sharp_Izq 3
#define Sharp_Der 1
#define Ultrasonic_Back 4
// Ultrasonic_Front_Left Ult_F_Izq
// Ultrasonic_Front_Right Ult_F_Der
//######################################################################################################################
//##                                      Variables Globales                                                          ##
//######################################################################################################################
int Sharp1_adc=0, Sharp2_adc=0, Sharp3_adc=0, Sharp4_adc=0;
float Sharp1_volt=0, Sharp2_volt=0, Sharp3_volt=0, Sharp4_volt=0;
int current_M1_adc=0, current_M2_adc=0;
float current_M1_volt=0, current_M2_volt=0;
float current_M1_curr=0, current_M2_curr=0;
int pwm1, pwm2;
String serial_buffer;
float x_acc=0, y_acc=0, z_acc=0;
float line_f_izq=0, line_f_der=0, line_b_izq=0, line_b_der=0;
float ult_f_der=0, ult_f_izq;
SPISettings settings(1000000, MSBFIRST, SPI_MODE0); //1MHz
int adc_state=0;
double deltaT, RPM_M1,  RPM_M2, cont_encoder1, cont_encoder2, copy_cont_encoder1, copy_cont_encoder2;
unsigned long ahora, pasado=0;
double deltaT_print;
unsigned long ahora_print, pasado_print=0;
double deltaT_motion;
unsigned long ahora_motion=0, pasado_motion=0;
bool enable_motion=LOW;
bool contador_ini=HIGH;
unsigned long ahora_contIni=0,pasado_contIni=0;
double deltaT_contIni=0;
//------------------------------ PID Motor 1 Motor Izquierdo  ----------------------------------------
//Define Variables we'll be connecting to
double Setpoint_M1, Input_M1, Output_M1;
//Specify the links and initial tuning parameters
double Kp_M1=2, Ki_M1=0.5, Kd_M1=0.1;
int out_limit_M1=255;
PID PID_M1(&Input_M1, &Output_M1, &Setpoint_M1, Kp_M1, Ki_M1, Kd_M1, DIRECT);
//------------------------------ PID Motor 2 Motor Derecho  -----------------------------------------
//Define Variables we'll be connecting to
double Setpoint_M2, Input_M2, Output_M2;
//Specify the links and initial tuning parameters
double Kp_M2=2, Ki_M2=0.5, Kd_M2=0.1;
int out_limit_M2=255;
PID PID_M2(&Input_M2, &Output_M2, &Setpoint_M2, Kp_M2, Ki_M2, Kd_M2, DIRECT);
//----------------------------        Control     ---------------------------------------------------
double des_RPM_left = 1000;
double des_RPM_right = 1000;
float V_center;
float W_center;
float V_left;
float V_right;
int time_control=0;
int time_control_max=100*1000;
int Vc=0;
int Wc=0;
int estado_controlador=0;
bool enable_giro90pos=LOW;
bool motores_activados=LOW;
unsigned long ticks_M1=0;
unsigned long ticks_M2=0;
float Dr_giro_90pos=0;
float recorrido_90pos=PI*25/4;
bool control_automatico=HIGH;   //Control Automático --> HIGH (PID + Vc,Wc), Control Manual --> LOW
bool enable_PID1=HIGH;
bool enable_PID2=HIGH;
int num_motores_activos_PID=2;
//######################################################################################################################
//##                                                    Main                                                          ##
//######################################################################################################################

void setup(){

  init_serial(9600);
  init_adcExt();
  init_sharps(A0, A1, A2, A3);
  init_current(A4, A5);
  Timer1.initialize(1000);// Interrupt every 1 ms
  Timer1.attachInterrupt(time_motion);

  pasado_contIni=millis();
}

void loop() {
   contador_inicial(3520);
   if(contador_ini==LOW && motores_activados==LOW){
      //Configuración inicial de los motores
      init_Motores();

      setDir_Motor(1,0);
      setDir_Motor(2,1);
      setPWM_Motor(1, 0);
      setPWM_Motor(2, 0);

      Input_M1=RPM_M1;
      Setpoint_M1 = 0;
      //turn the PID on
      PID_M1.SetMode(AUTOMATIC);
      Input_M2=RPM_M2;
      Setpoint_M2 = 0;
      //turn the PID on
      PID_M2.SetMode(AUTOMATIC);
      enable_giro90pos=HIGH;
      //-----------------------------------------
      motores_activados=HIGH;
   }
   measure_sharps_raw(SHARP_1, SHARP_2, SHARP_3, SHARP_4);  //Mide los datos de A0, A1, A2, A3, donde estan los 4 sharps
   measureAll_adcExt();                                     //Mide los datos del acelerómetro (eje x, y,z) y los detectores de linea

   if(motores_activados==HIGH){
     measure_current(CURRENT_M1,CURRENT_M2);
     detect_limit_current();
     measure_rpm();
     //set_PID_motores(num_motores_activos_PID,enable_PID1,enable_PID2);
     //send_serial();
     //estrategia();
     //maquina_estados();

     if(enable_motion){
      ahora_motion = millis();
      deltaT_motion= ahora_motion - pasado_motion;
      if(deltaT_motion>= 500){
        estado_controlador=0;
        enable_motion=LOW;
        enable_PID1=HIGH;
        enable_PID2=HIGH;
        num_motores_activos_PID=2;
      }
    }else{
      estrategia();
      set_PID_motores(num_motores_activos_PID,enable_PID1,enable_PID2);
      maquina_estados();
    }
    //serial();           //Lee los comandos por serial
  }
}

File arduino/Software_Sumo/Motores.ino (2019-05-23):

//######################################################################################################################
//##                                                  Motores                                                         ##
//######################################################################################################################

/*########################################################################################
## ------------------------------    init_Motores    ---------------------------------- ##
##                                                                                      ##
## Esta función se utiliza para configurar los puertos del micro que manejan los motores##
## configura los puertos del encoder (ENC_M), el pwm (PWM_M), el pin de encendido y     ##
## apagado (EN_M), y el cambio de dirección, forward/reverse (FR_M). Luego  se establece##
## la configuración inicial, se establece la dirección, un PWM cero para cada motor, y  ##
## luego se habilitan los motores                                                       ##
##                                                                                      ##
##------------------------------------Variables---------------------------------------- ##
##                                                                                      ##
## Tamaño   Nombre      Tipo      Función                                               ##
##                                                                                      ##
########################################################################################*/

void init_Motores(){
    //----------------  Configuración de los pines      ------------------------
    pinMode(ENC_M1,INPUT);
    attachInterrupt(digitalPinToInterrupt(ENC_M1),tick_M1,FALLING);
    pinMode(ENC_M2,INPUT);
    attachInterrupt(digitalPinToInterrupt(ENC_M2),tick_M2,FALLING);
    pinMode(PWM_M1,OUTPUT);
    pinMode(PWM_M2,OUTPUT);
    pinMode(EN_M1,OUTPUT);
    pinMode(EN_M2,OUTPUT);
    pinMode(FR_M1,OUTPUT);
    pinMode(FR_M2,OUTPUT);

    //----------------  Configuración inicial de los motores ---------------------
    //Se inician ambos motores deshabilitados.
    enable_motor(1,0);    //Motor 1 apagado
    enable_motor(2,0);    //Motor 2 apagado
    //Sentido de Giro de cada motor contrario el uno del otro para desplazamiento
    //en un solo sentido.
    setDir_Motor(1,0);
    setDir_Motor(2,1);
    //PWM de cada motor
    setPWM_Motor(1, 0);   //PWM de inicio 0%
    setPWM_Motor(2, 0);   //PWM de inicio 0%
    //Se habilitan ambos motores deshabilitados.
    enable_motor(1,1);    //Motor 1 encendido
    enable_motor(2,1);    //Motor 2 encendido
}

/*########################################################################################
## ------------------------------    enable_motor    ---------------------------------- ##
##                                                                                      ##
## Esta función se utiliza para encender o apagar los motores (motor 1 y motor 2)       ##
## con enable==1 coloca 5 voltios en el pin ON/OFF del motor y con enable==0            ##
## coloca 0 voltios en el pin respectivo                                                ##
##                                                                                      ##
##------------------------------------Variables---------------------------------------- ##
##                                                                                      ##
## Tamaño   Nombre      Tipo      Función                                               ##
##                                                                                      ##
## int      num_motor   Entrada   - 1 o 2, representa el número del motor a utilizar    ##
## int      enable      Entrada   - 0 para apagar y 1 para encender                     ##
##                                                                                      ##
########################################################################################*/

void enable_motor(int num_motor, int enable){
  switch(num_motor){
    case 1:         //Para el Motor 1
      if(enable==0){
        digitalWrite(EN_M1,LOW);
      }else{
        digitalWrite(EN_M1,HIGH);
      }
    break;
    case 2:         //Para el Motor 2
      if(enable==0){
        digitalWrite(EN_M2,LOW);
      }else{
        digitalWrite(EN_M2,HIGH);
      }
    break;
  }
}

/*########################################################################################
## ------------------------------    setPWM_Motor    ---------------------------------- ##
##                                                                                      ##
## Esta función se utiliza para aplicar una señal pwm (con analogWrite) a los motores   ##
## (1 o 2)                                                                              ##
##                                                                                      ##
##------------------------------------Variables---------------------------------------- ##
##                                                                                      ##
## Tamaño   Nombre      Tipo      Función                                               ##
##                                                                                      ##
## int      num_motor   Entrada   - 1 o 2, representa el número del motor a utilizar    ##
## int      pwm_        Entrada   - numero entre 0 y 255, donde 0 es el valor min y 255 ##
##                                  el valor max                                        ##
##                                                                                      ##
########################################################################################*/

void setPWM_Motor(int num_motor, int pwm_){
switch(num_motor){
    case 1:         //Para el Motor 1
      analogWrite(PWM_M1,pwm_);
      pwm1=pwm_;
    break;

    case 2:         //Para el Motor 2
       analogWrite(PWM_M2,pwm_);
       pwm2=pwm_;
    break;
  }
}
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

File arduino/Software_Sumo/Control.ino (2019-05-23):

//######################################################################################################################
//##                                   Modelo de Drive Diferencial                                                    ##
//######################################################################################################################
//-------------                         Definir la RPM desada para cada motor                  -------------------------
void set_desRPM(float V, float W){
  //Unicycle
  V_right=Vright_unicycle(V, W);
  V_left=Vleft_unicycle(V, W);
  //------  Motor 1 -----------------------------
  if(V_right>=0){
    setDir_Motor(1,0);
    des_RPM_right=RPM_from_VEL(V_right);
  }else{
    setDir_Motor(1,1);
    des_RPM_right=RPM_from_VEL(abs(V_right));
  }
  //------  Motor 2 -----------------------------
  if(V_left>=0){
    setDir_Motor(2,1);
    des_RPM_left=RPM_from_VEL(V_left);
  }else{
    setDir_Motor(2,0);
    des_RPM_left=RPM_from_VEL(abs(V_left));
  }
}
//-------------                       Conversión de Vleft a RPM1 y Vright a RPM2                ------------------------
double RPM_from_VEL(float V){
  //Convertimos de V (m/s) a W (rad/s)
  float W = V/RADIUS_WHEEL;
  //Convertimos de rad/s a rev/min 
  double RPM = W*9.5492;
  return RPM;
}
//--------------  Conversión del modelo de uniciclo V,W al modelo de drive diferencial Vr,Vl  --------------------------
//-------------                       Conversión de V,W a Vleft y V,W a Vright                 -------------------------
float Vright_unicycle(float V, float W){              //V en m/s y W en rad/s, Vright en rad/s
  return (((2*V)+(W*LENGTH_ROBOT))/(2*RADIUS_WHEEL));
}

float Vleft_unicycle(float V, float W){                   //V en m/s y W en rad/s, Vleft en rad/s
  return ((2*V)-(W*LENGTH_ROBOT))/(2*RADIUS_WHEEL);
}
//------------  Manejo del tiempo para definir angulos y distancias en lugar de velocidades   --------------------------

void time_motion(){
  if(time_control<time_control_max){
    time_control=time_control+1;
  }else{
    time_control=0;
    motion();
  }
}

void motion(){
  //Vc=0;
  //Wc=0;
}

void maquina_estados(){
  if(estado_controlador==0){
    search_izq();
  }else if(estado_controlador==1){
    kill();
  }else if(estado_controlador==2){
    off();
  }else if(estado_controlador==3 && enable_giro90pos==HIGH){
    giro_90pos();
  }else if(estado_controlador==4){
    search_der();
  }else if(estado_controlador==5){
    kill_izq();
  }else if(estado_controlador==6){
    kill_der();
  }
}

void set_PID_motores(int motores_activos,bool enable_motor_1, bool enable_motor_2){
  if(motores_activos==2){ //2 motores activos
    set_desRPM(Vc, Wc);
    
    //PID Vel Motor 1
    Setpoint_M1=map(des_RPM_left, 0, RPM_MAX, 0, 255); 
    Input_M1=map(RPM_M1, 0, RPM_MAX, 0, 255); 
    PID_M1.Compute();
    setPWM_Motor(1, Output_M1);
     
    //PID Vel Motor 2
    Setpoint_M2 = map(des_RPM_right, 0, RPM_MAX, 0, 255); 
    Input_M2=map(RPM_M2, 0, RPM_MAX, 0, 255); 
    PID_M2.Compute();
    setPWM_Motor(2, Output_M2);
  }else{                //Un motor activo
    if(enable_motor_1==HIGH && enable_motor_2==LOW){
      set_desRPM(Vc, Wc);
      
      //PID Vel Motor 1
      Setpoint_M1=map(des_RPM_left, 0, RPM_MAX, 0, 255); 
      Input_M1=map(RPM_M1, 0, RPM_MAX, 0, 255); 
      PID_M1.Compute();
      setPWM_Motor(1, Output_M1);
       
      //PID Vel Motor 2 es cero
      setPWM_Motor(2, 0);
    }else if(enable_motor_1==LOW && enable_motor_2==HIGH){
      set_desRPM(Vc, Wc);
      
      //PID Vel Motor 1
      setPWM_Motor(1, 0);
       
      //PID Vel Motor 2
      Setpoint_M2 = map(des_RPM_right, 0, RPM_MAX, 0, 255); 
      Input_M2=map(RPM_M2, 0, RPM_MAX, 0, 255); 
      PID_M2.Compute();
      setPWM_Motor(2, Output_M2);
    }
  }
}

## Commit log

2019-05-23 Adding 3D models and electronic designs
    [3xNanoV3.0ATmega328.SLDPRT, AcopleBaseMotorSumo.SLDPRT, AdactadorRuedaEjeSumo.SLDPRT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]
2019-05-23 Changing spaces for underscores
    [3xNanoV3.0ATmega328.SLDPRT, AcopleBaseMotorSumo.SLDPRT, AdactadorRuedaEjeSumo.SLDPRT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]
